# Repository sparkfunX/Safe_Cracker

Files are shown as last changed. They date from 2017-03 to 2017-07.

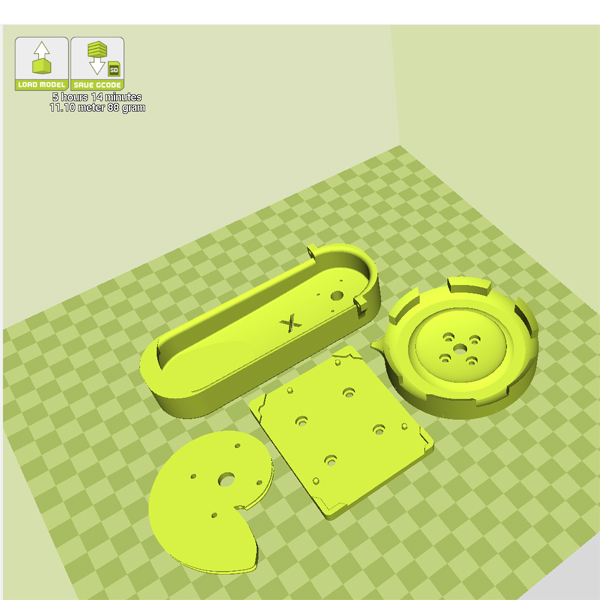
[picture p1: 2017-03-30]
3D/Safe3Dpieces.jpg

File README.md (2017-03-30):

SparkFun Safe Cracker
===========================================================

SparkFun Safe Cracker

A robot with some tricks to open combination safes.

We were able to crack our Craigslist safe in 40 minutes and 42 seconds! You can [re-watch the live cracking](https://www.youtube.com/watch?v=AsVSEHv2N4M) if you'd like. The magic moment occurs at [45:20](https://www.youtube.com/watch?v=AsVSEHv2N4M&t=45m10s) but start around [44:30](https://www.youtube.com/watch?v=AsVSEHv2N4M&t=44m30s) to get the full scope of what's going on.

The full tutorial is [here](https://learn.sparkfun.com/tutorials/building-a-safe-cracking-robot).

Repository Contents
-------------------

* **/Hardware** - The layout of the Safe Cracker shield in EAGLE PCB
* **/Firmware** - Source code that runs on the [RedBoard](https://www.sparkfun.com/products/13975)
* **/3D** - STL files for the dial coupler, handle puller, nautilus horn, and electronics base plate
* **live_crack_serial.log** - Output from the robot during the live stream.

License Information
-------------------

This project is _**open source**_! 

Please use, reuse, and modify these files as you see fit. Please maintain attribution to SparkFun Electronics and release anything derivative under the same license.

Distributed as-is; no warranty is given.

- Your friends at SparkX

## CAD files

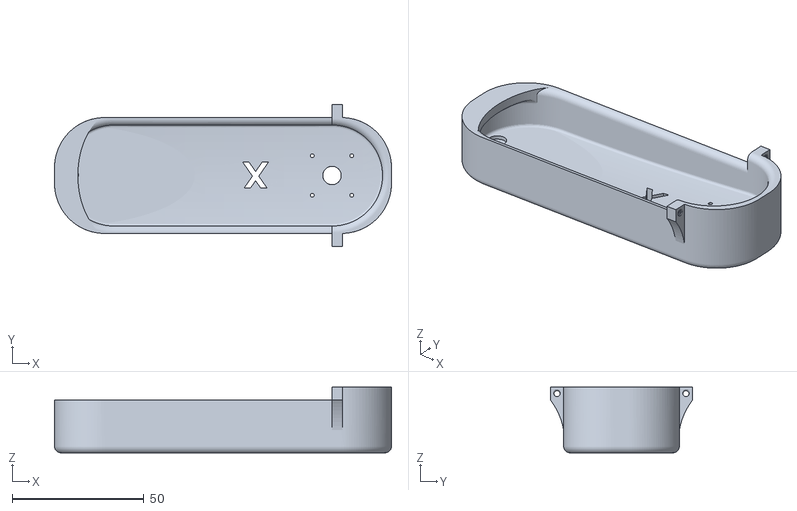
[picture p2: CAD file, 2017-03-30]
3D/SafeHandleMain.stl
128.0 x 53.9 x 25.0

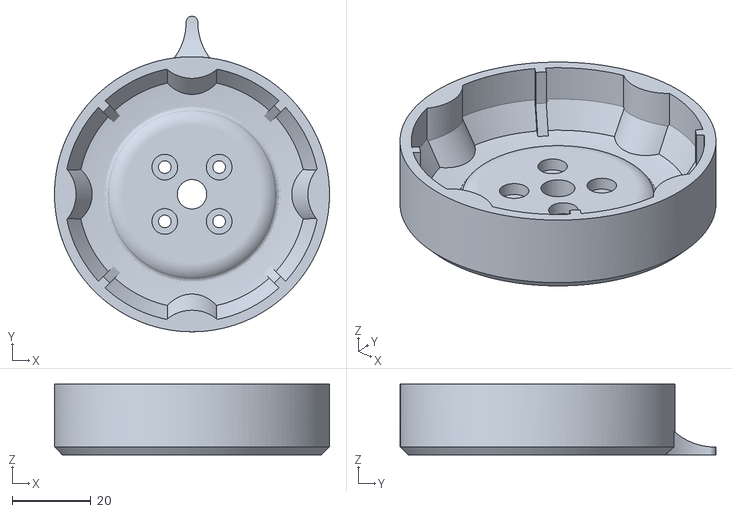
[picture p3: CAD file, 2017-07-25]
3D/DialForNewSentrySafe.stl
70.0 x 80.3 x 18.0

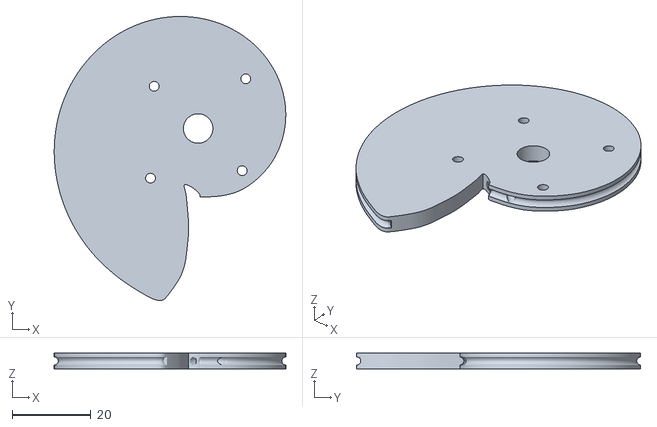
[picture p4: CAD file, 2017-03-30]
3D/NautilusPulley.stl
58.9 x 72.2 x 4.00

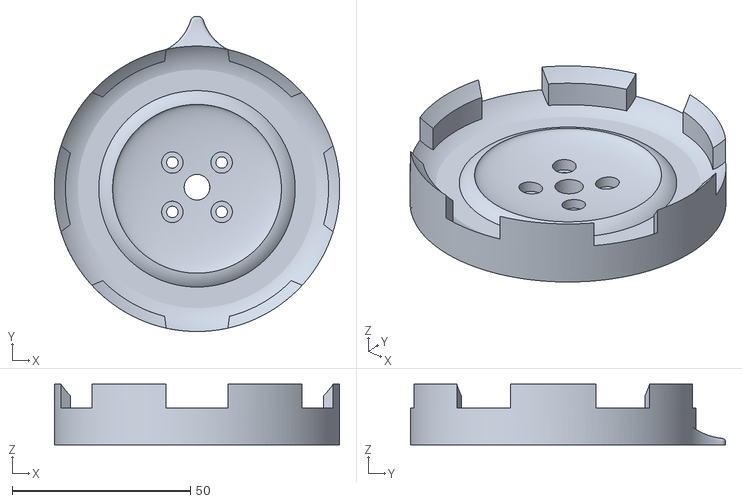
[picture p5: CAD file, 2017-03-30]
3D/SafeCrackerDial3.stl
80.0 x 88.3 x 17.0

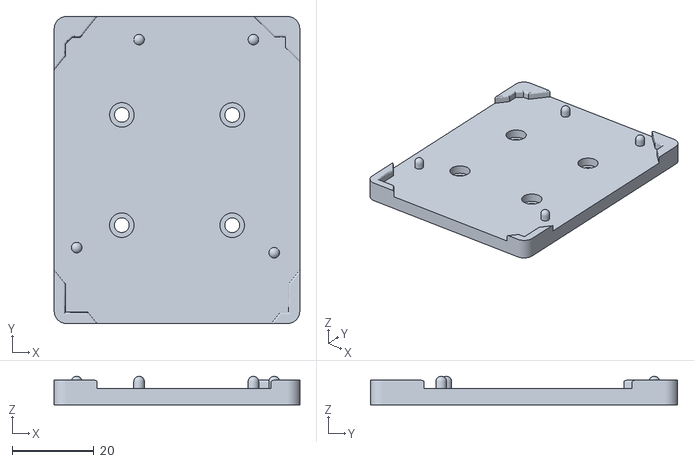
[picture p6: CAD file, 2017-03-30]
3D/SafeCrackerArduinoMount.stl
60.0 x 75.0 x 6.97

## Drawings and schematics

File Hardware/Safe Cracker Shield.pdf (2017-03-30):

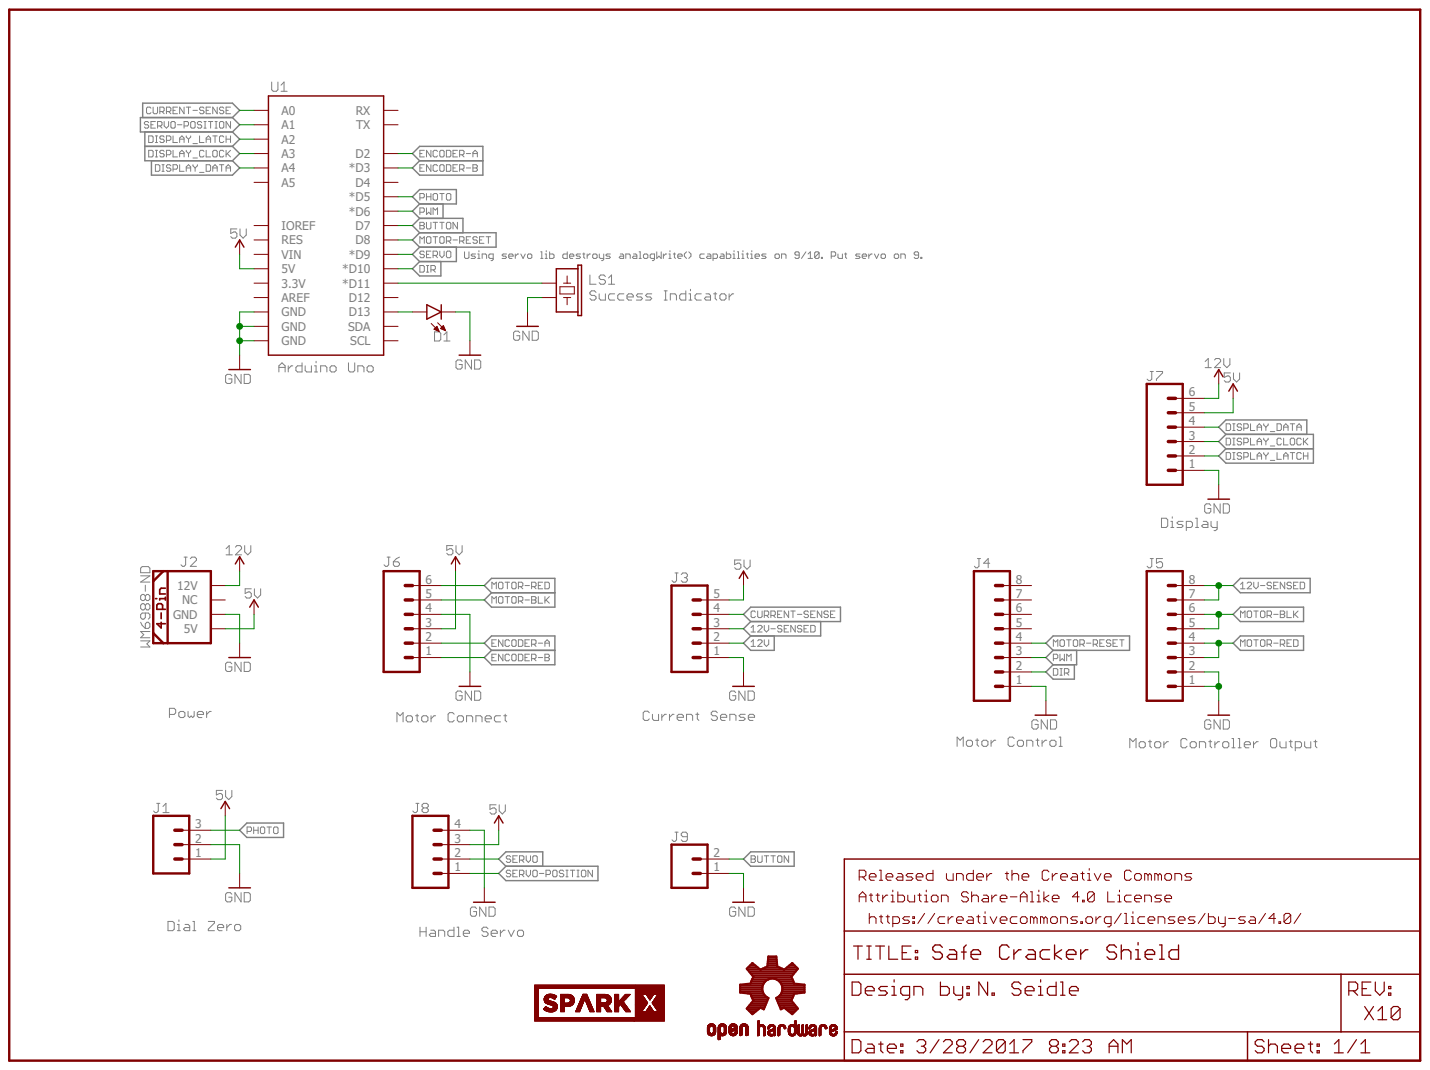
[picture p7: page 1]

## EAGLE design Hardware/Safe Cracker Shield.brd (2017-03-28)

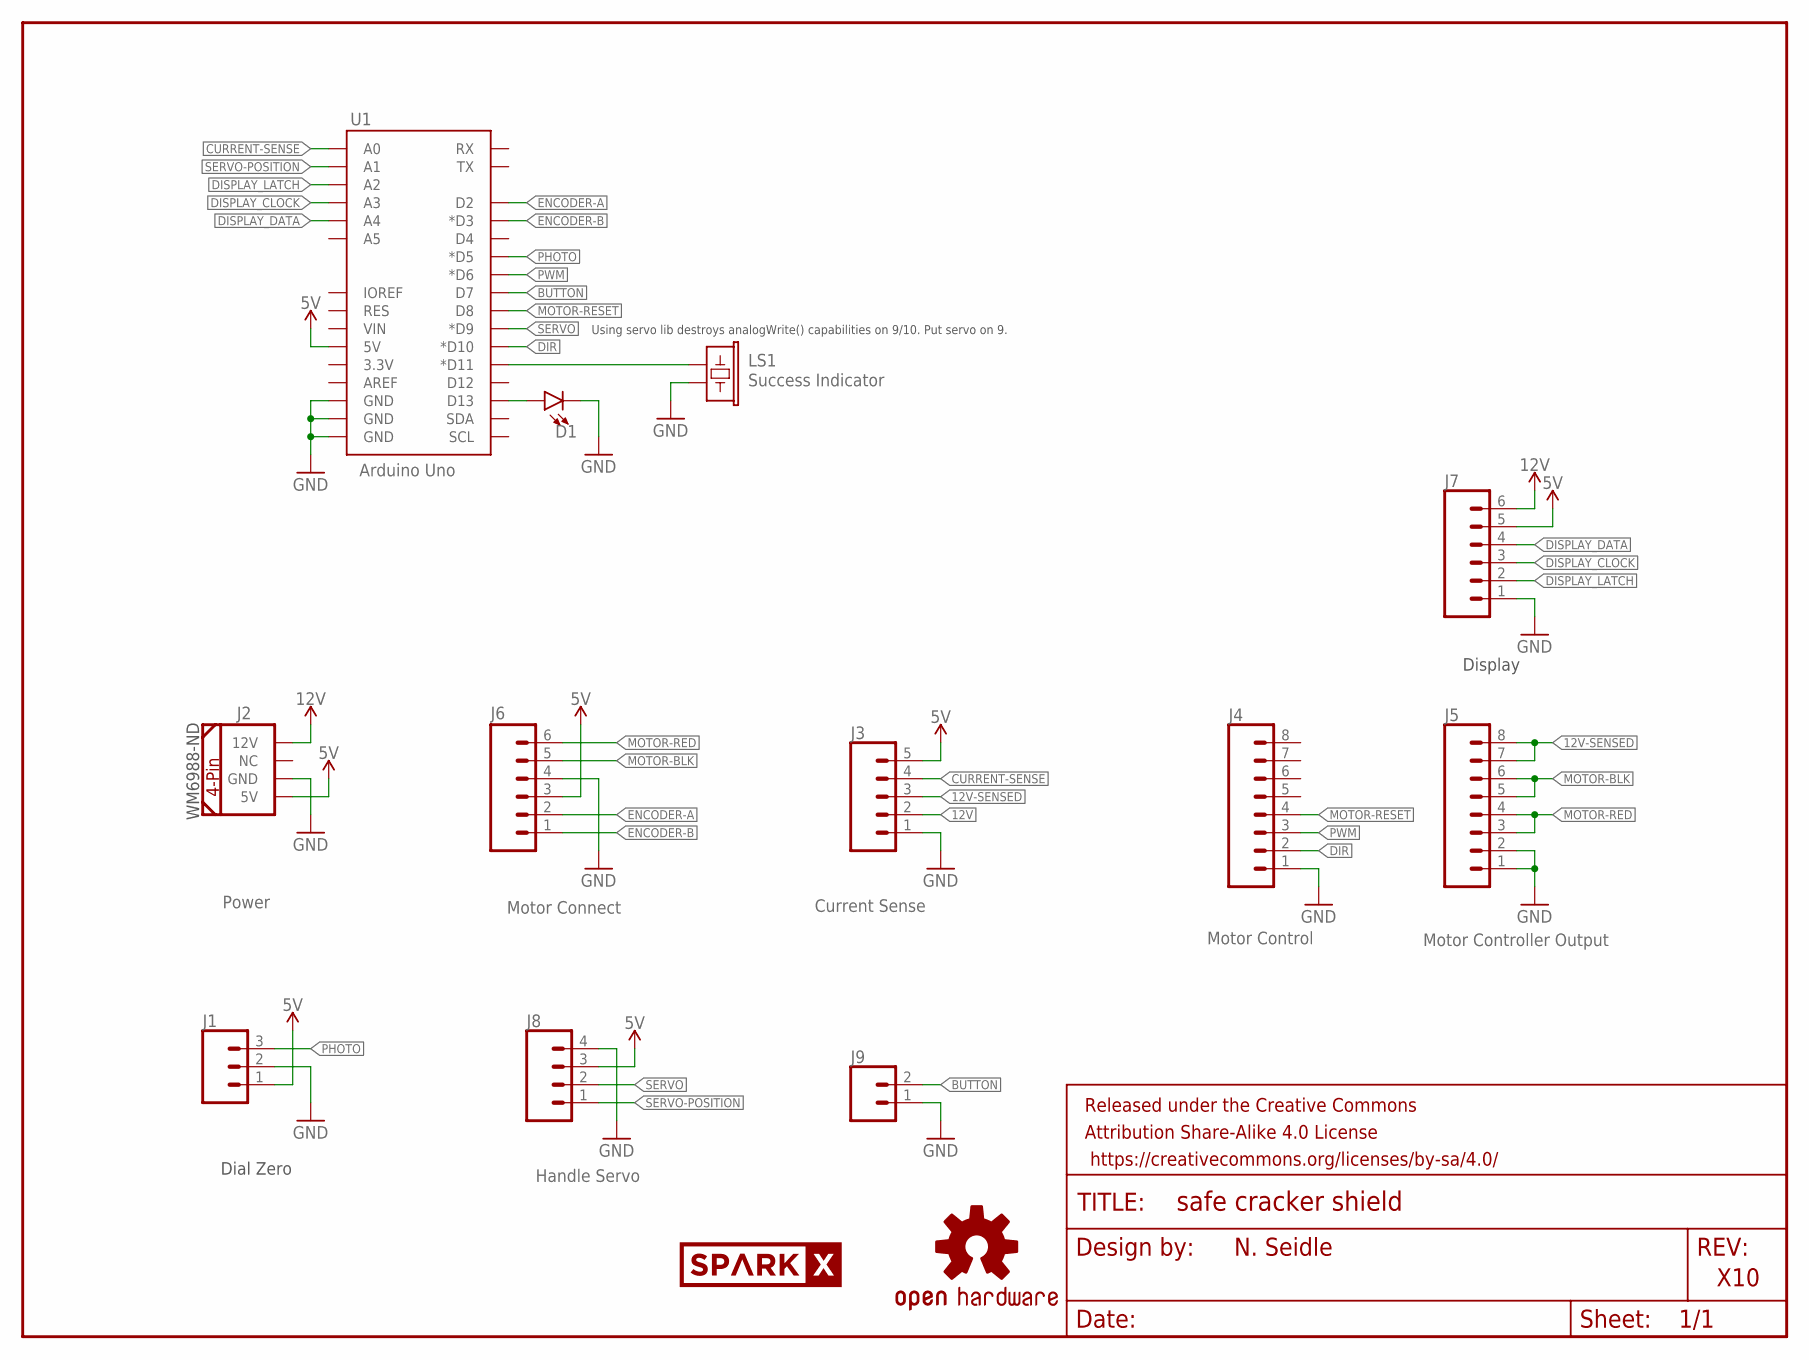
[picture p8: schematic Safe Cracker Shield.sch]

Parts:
D1: LED5MM; LED_5MM
FRAME1: FRAME-LETTER; CREATIVE_COMMONS
J1: CONN_03JST-PTH-VERT; JST-3-PTH-VERT
J2: Power; COMPUTER-PERIPHERAL-POWER-RA
J3: Current Sense; 1X05
J4: Motor Control; 1X08
J5: Motor Controller Output; 1X08
J6: Motor Connect; 1X06@1
J7: CONN_06SILK_FEMALE_PTH; 1X06
J8: Handle Servo; 1X04
J9: CONN_02JST-PTH-VERT; JST-2-PTH-VERT
LOGO2: OSHW-LOGOS; OSHW-LOGO-S
LS1: Success Indicator; BUZZER-12MM
U1: Arduino Uno; UNO_R3_SHIELD_NOLABELS
U$1: SPARKX-LOGO5; SPARKX-LARGE

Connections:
5V: J1.1, J2.5V, J3.5, J6.3, J7.5, J8.3, U1.5V
12V: J2.12V, J3.2, J7.6
12V-SENSED: J3.3, J5.7, J5.8
BUTTON: J9.2, U1.D7
BUZZ: LS1.+ (1), U1.D11 (*D11)
CURRENT-SENSE: J3.4, U1.A0
DIR: J4.2, U1.D10 (*D10)
DISPLAY_CLOCK: J7.3, U1.A3
DISPLAY_DATA: J7.4, U1.A4
DISPLAY_LATCH: J7.2, U1.A2
ENCODER-A: J6.2, U1.D2
ENCODER-B: J6.1, U1.D3 (*D3)
GND: D1.K (C), J1.2, J2.GND, J3.1, J4.1, J5.1, J5.2, J6.4, J7.1, J8.4, J9.1, LS1.- (2), U1.GND@0 (GND), U1.GND@1 (GND), U1.GND@2 (GND)
MOTOR-BLK: J5.5, J5.6, J6.5
MOTOR-RED: J5.3, J5.4, J6.6
MOTOR-RESET: J4.4, U1.D8
unnamed: D1.A, U1.D13
PHOTO: J1.3, U1.D5 (*D5)
PWM: J4.3, U1.D6 (*D6)
SERVO: J8.2, U1.D9 (*D9)
SERVO-POSITION: J8.1, U1.A1

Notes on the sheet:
WM6988-ND
N. Seidle
X10
Using servo lib destroys analogWrite() capabilities on 9/10. Put servo on 9.
Dial Zero
Display

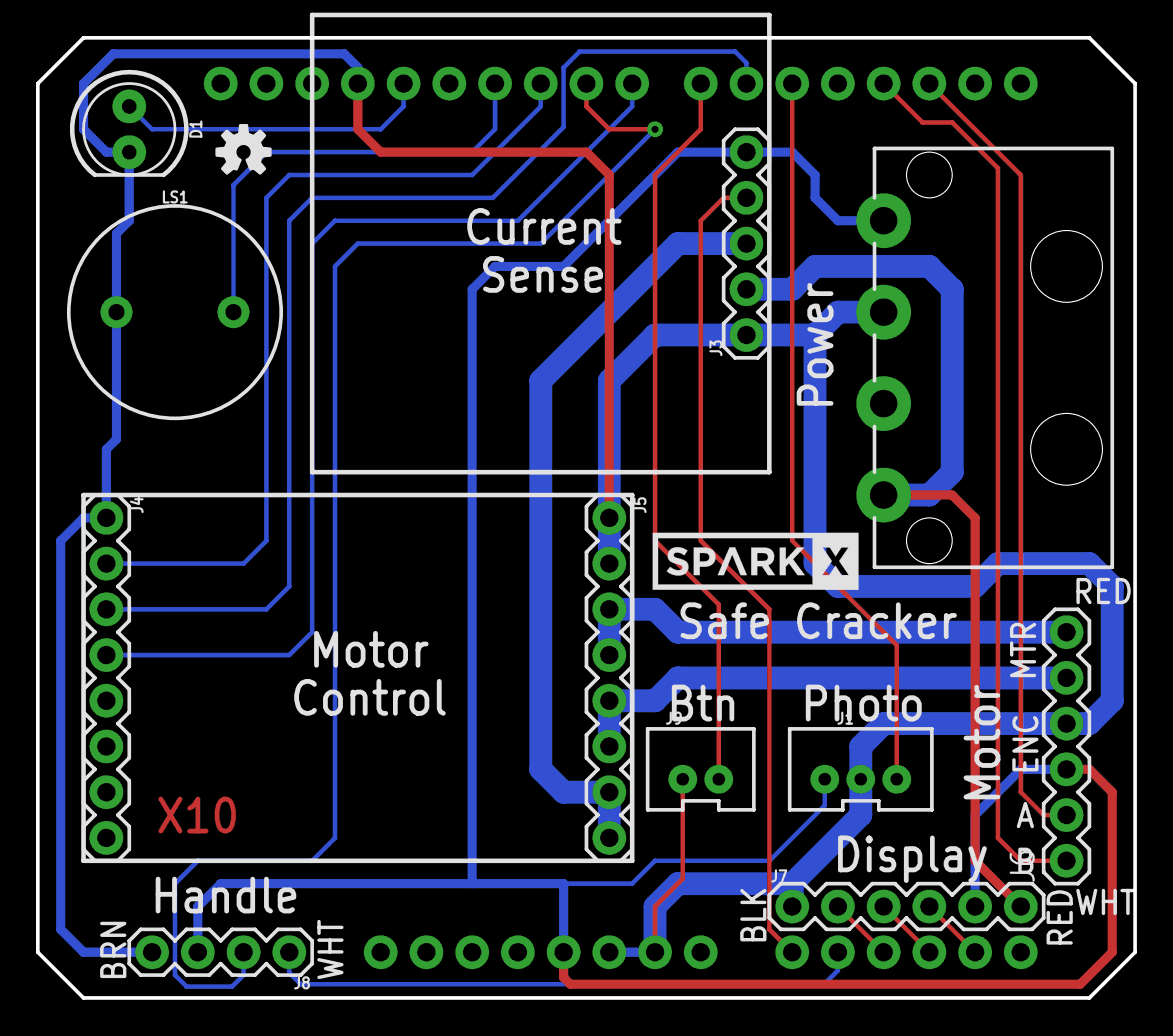
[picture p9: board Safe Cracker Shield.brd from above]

Board: 2 copper layers, 61.0 x 53.3 mm, 15 parts (0 on the bottom side), 21 nets.

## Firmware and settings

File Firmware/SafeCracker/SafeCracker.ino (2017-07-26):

/*
  Opening a safe using a motor and a servo
  By: Nathan Seidle @ SparkFun Electronics
  Date: February 24th, 2017

  We use a motor with encoder feedback to try to glean the internal workings of the
  safe to reduce the overall solution domain. Then we begin running through
  solution domain, pulling on the handle and measuring it as we go.

  Motor current turning dial, speed = 255, ~350 to 560mA
  Motor current turning dial, speed = 50, = ~60 to 120mA

  TODO:
  servo rest, pull, and open settings to eeprom
  current combination to nvm
*/

#include "nvm.h" //EEPROM locations for settings
#include <EEPROM.h> //For storing settings and things to NVM

#include <Servo.h>
Servo handleServo;

//Pin definitions
const byte encoderA = 2;
const byte encoderB = 3;
const byte photo = 5;
const byte motorPWM = 6;
const byte button = 7;
const byte motorReset = 8;
const byte servo = 9;
const byte motorDIR = 10;
const byte buzzer = 11;
const byte LED = 13;

const byte currentSense = A0;
const byte servoPositionButton = A1;
const byte displayLatch = A2;
const byte displayClock = A3;
const byte displayData = A4;

//Servo values are found using the testServo() function while the
//cracker was deattached from the safe

//Default settings for 0.8 cubic ft. safe
//On the 1st configuration increasing numbers cause handle to go down
//const byte servoRestingPosition = 15; //Position not pulling/testing on handle
//const byte servoPressurePosition = 50; //Position when doing indent measuring
//const byte servoTryPosition = 80; //Position when testing handle

//Default settings for 1.2 cubic ft. safe
//On the 2nd larger configuration, decreasing numbers cause handle to go down
int servoRestingPosition = 100; //Position not pulling/testing on handle
int servoTryPosition = 50; //Position when testing handle
int servoHighPressurePosition = 40; //Position when doing indent measuring

const int timeServoApply = 350;  //ms for servo to apply pressure. 350 works
const int timeServoRelease = 250;  //Allow servo to release. 250 works
const int timeMotorStop = 125; //ms for motor to stop spinning after stop command. 200 works

int handlePosition; //Used to see how far handle moved when pulled on
//const int handleOpenPosition = 187; //Analog value. Must be less than analog value from servo testing.

#define CCW 0
#define CW 1

volatile int steps = 0; //Keeps track of encoder counts. 8400 per revolution so this can get big.
boolean direction = CW; //steps goes up or down based on direction
boolean previousDirection = CW; //Detects when direction changes to add some steps for encoder slack
byte homeOffset = 0; //Found by running findFlag(). Stored in nvm.

//Because we're switching directions we need to add extra steps to take
//up the slack in the encoder
//The greater the adjustment the more negative it goes
int switchDirectionAdjustment = (84 * 0) + 0; //Use 'Test dial control' to determine adjustment size
//84 * 1 - 20 = Says 34 but is actually 33.5 (undershoot)
//84 * 0 = Says 85 but is actually 85.9 (overshoot)

//DiscA goes in CCW fashion during testing, increments 3 each new try.
//We don't know if this is the center of the notch. If you exhaust the combination domain, adjust up or down one.
#define DISCA_START 0

//DiscB goes in CW fashion during testing, increments 3 each new try.
#define DISCB_START (DISCA_START - 3)

//DiscC goes in CCW fashion during testing. 12 indentations, 12 raised bits. Indents are 4.17 numbers wide.
#define DISCC_START 0

//These are the combination numbers we are attempting
int discA = DISCA_START;
int discB = DISCB_START;
int discC = DISCC_START;

//int discA = 30; //Testing only. Don't use.
//int discB = 55;
//int discC = 47;

//Keeps track of the combos we need to try for each disc
//byte maxAAttempts = 33; //Assume solution notch is 3 digits wide
//byte maxBAttempts = 33; //Assume solution notch is 3 digits wide
byte maxCAttempts = 0; //Calculated at startup

//Keeps track of how many combos we've tried on a given disc
//byte discAAttempts = 0;
//byte discBAttempts = 0;
byte discCAttempts = 0;

long startTime; //Used to measure amount of time taken per test

boolean buttonPressed = false; //Keeps track of the 'GO' button.

boolean indentsToTry[12]; //Keeps track of the indents we want to try
int indentLocations[12]; //Encoder click for a given indent
int indentWidths[12]; //Calculated width of a given indent
int indentDepths[12]; //Not really used

void setup()
{
  Serial.begin(115200);
  Serial.println();
  Serial.println();
  Serial.println("Safe Cracker");

  pinMode(motorReset, OUTPUT);
  disableMotor();

  pinMode(encoderA, INPUT);
  pinMode(encoderB, INPUT);

  pinMode(motorPWM, OUTPUT);
  pinMode(motorDIR, OUTPUT);

  pinMode(LED, OUTPUT);

  pinMode(currentSense, INPUT);
  pinMode(servoPositionButton, INPUT_PULLUP);

  pinMode(photo, INPUT_PULLUP);

  pinMode(button, INPUT_PULLUP);

  pinMode(displayClock, OUTPUT);
  pinMode(displayLatch, OUTPUT);
  pinMode(displayData, OUTPUT);

  digitalWrite(displayClock, LOW);
  digitalWrite(displayLatch, LOW);
  digitalWrite(displayData, LOW);

  //Setup the encoder interrupts.
  attachInterrupt(digitalPinToInterrupt(encoderA), countA, CHANGE);
  attachInterrupt(digitalPinToInterrupt(encoderB), countB, CHANGE);

  //Load settings from EEPROM
  homeOffset = EEPROM.read(LOCATION_HOME_OFFSET); //After doing a findFlag calibration, adjust this number up or down until dial is at zero
  Serial.print(F("Home Offset: "));
  Serial.println(homeOffset);

  Serial.println(F("Indent data"));
  for (int indentNumber = 0 ; indentNumber < 12 ; indentNumber++)
  {
    //Load the yes/no for each indent To Try
    indentsToTry[indentNumber] = EEPROM.read(LOCATION_TEST_INDENT_0 + indentNumber); //Boolean
    
    //Get the encoder values for each indent
    EEPROM.get(LOCATION_INDENT_DIAL_0 + (indentNumber * 2), indentLocations[indentNumber]); //Addr, loc. Encoder click for a given indent

    Serial.print(F("IndentNum["));
    Serial.print(indentNumber);
    Serial.print(F("] Encoder["));
    Serial.print(indentLocations[indentNumber]);
    Serial.print(F("] / Dial["));
    Serial.print(convertEncoderToDial(indentLocations[indentNumber]));
    Serial.print(F("] / Width["));
    Serial.print(indentWidths[indentNumber]);
    Serial.print(F("] / Depth["));
    Serial.print(indentDepths[indentNumber]);
    Serial.print(F("] Test["));

    //Print Test if indent will be tested
    if (indentsToTry[indentNumber] == true) Serial.print("Y");
    else Serial.print("N");
    Serial.print(F("]"));

    Serial.println();

  }

  //Get servo settings
  EEPROM.get(LOCATION_SERVO_REST, servoRestingPosition);
  EEPROM.get(LOCATION_SERVO_TEST_PRESSURE, servoTryPosition);
  EEPROM.get(LOCATION_SERVO_HIGH_PRESSURE, servoHighPressurePosition);

  //Validate settings
  if (servoRestingPosition > 250 || servoRestingPosition < 0)
  {
    //New board and/or EEPROM has not been set
    //Assign defaults
    servoRestingPosition = 100;
    servoTryPosition = 50;
    servoHighPressurePosition = 40;

    //Record these defaults to EEPROM
    EEPROM.put(LOCATION_SERVO_REST, servoRestingPosition); //addr, data
    EEPROM.put(LOCATION_SERVO_TEST_PRESSURE, servoTryPosition);
    EEPROM.put(LOCATION_SERVO_HIGH_PRESSURE, servoHighPressurePosition);
  }

  Serial.print(F("servo: resting["));
  Serial.print(servoRestingPosition);
  Serial.print(F("] try["));
  Serial.print(servoTryPosition);
  Serial.print(F("] HighPressure["));
  Serial.print(servoHighPressurePosition);
  Serial.print(F("]"));
  Serial.println();

  //Setup servo
  handleServo.attach(servo);
  handleServo.write(servoRestingPosition); //Goto the resting position (handle horizontal, door closed)
  delay(timeServoRelease * 3); //Allow servo to release, may be in solution slot

  randomSeed(analogRead(A5));

  //Calculate how many indents we need to attempt on discC
  maxCAttempts = 0;
  for (byte x = 0 ; x < 12 ; x++)
    if (indentsToTry[x] == true) maxCAttempts++;

  //At startup discB may be negative. Fix it.
  if (discB < 0) discB += 100;

  //Tell dial to go to zero
  enableMotor(); //Turn on motor controller
  findFlag(); //Find the flag
  //Adjust steps with the real-world offset
  steps = (84 * homeOffset); //84 * the number the dial sits on when 'home'
  setDial(0, false); //Make dial go to zero

  clearDisplay();
  showCombination(0, 0, 0); //Display zeroes
}

void loop()
{
  char incoming;

  //Main serial control menu
  Serial.println();
  Serial.print(F("Combo to start at: "));
  Serial.print(discA);
  Serial.print("/");
  Serial.print(discB);
  Serial.print("/");
  Serial.print(discC);
  Serial.println();

  Serial.println(F("1) Go home and reset dial"));
  Serial.println(F("2) Test dial control"));
  Serial.println(F("3) View indent positions"));
  Serial.println(F("4) Measure indents"));
  Serial.println(F("5) Set indents to test"));
  Serial.println(F("6) Set starting combos"));
  Serial.println(F("7) Calibrate handle servo"));
  Serial.println(F("8) Test handle button"));
  Serial.println(F("9) Test indent centers"));
  Serial.println(F("s) Start cracking"));

  while (!Serial.available())
  {
    if (digitalRead(button) == LOW)
    {
      delay(50);
      if (digitalRead(button) == LOW)
      {
        buttonPressed = true;
        break;
      }
      else
      {
        buttonPressed = false;
      }
    }
    else
    {
      buttonPressed = false;
    }
  }

  if (buttonPressed == true)
  {
    Serial.println(F("Button pressed!"));

    while (digitalRead(button) == false); //Wait for user to stop pressing button
    buttonPressed = false; //Reset variable

    incoming = 's'; //Act as if user pressed start cracking
  }
  else
  {
    incoming = Serial.read();
  }

  if (incoming == '1')
  {
    //Go to starting conditions
    findFlag(); //Detect the flag and center the dial

    Serial.print(F("Home offset is: "));
    Serial.println(homeOffset);

    int zeroLocation = 0;
    while (1) //Loop until we have good input
    {
      Serial.print(F("Enter where dial is actually at: "));

      while (!Serial.available()); //Wait for user input

      Serial.setTimeout(1000); //Must be long enough for user to enter second character
      zeroLocation = Serial.parseInt(); //Read user input

      Serial.print(zeroLocation);
      if (zeroLocation >= 0 && zeroLocation <= 99) break;
      Serial.println(F(" out of bounds"));
    }

    homeOffset = zeroLocation;

    Serial.print(F("\n\rSetting home offset to: "));
    Serial.println(homeOffset);

    EEPROM.write(LOCATION_HOME_OFFSET, homeOffset);

    //Adjust steps with the real-world offset
    steps = (84 * homeOffset); //84 * the number the dial sits on when 'home'

    setDial(0, false); //Turn to zero

    Serial.println(F("Dial should be at: 0"));
  }
  else if (incoming == '2')
  {
    positionTesting(); //Pick random places on dial and prove we can go to them
  }
  else if (incoming == '3')
  {
    //View indent center values
    for (int x = 0 ; x < 12 ; x++)
    {
      Serial.print(x);
      Serial.print(F(": ["));
      Serial.print(lookupIndentValues(x));
      Serial.print(F("]"));
      Serial.println();
    }
  }
  else if (incoming == '4')
  {
    //Measure indents

    int measurements = 0;
    while (1) //Loop until we have good input
    {
      Serial.print(F("How many measurements would you like to take? (Start with 1)"));
      while (!Serial.available()); //Wait for user input
      Serial.setTimeout(1000); //Must be long enough for user to enter second character
      measurements = Serial.parseInt(); //Read user input

      if (measurements >= 1 && measurements <= 20) break;

      Serial.print(measurements);
      Serial.println(F(" out of bounds"));
    }
    Serial.println(measurements);

    measureDiscC(measurements); //Try to measure the idents in disc C. Give function the number of tests to run (get average).
  }
  else if (incoming == '5')
  {
    while (1) //Loop until exit
    {
      int indent = 0;
      while (1) //Loop until we have valid input
      {
        Serial.println("Indents to test:");
        for (int x = 0 ; x < 12 ; x++)
        {
          Serial.print(x);
          Serial.print(": ");

          //Print Test if indent will be tested
          if (indentsToTry[x] == true) Serial.print("Y");
          else Serial.print("N");

          //Print dial value of this indent
          Serial.print(" / ");
          Serial.print(convertEncoderToDial(indentLocations[x]));

          Serial.println();
        }
        Serial.println("Which indent to change?");
        Serial.println("Type 99 to exit");

        while (!Serial.available()); //Wait for user input

        Serial.setTimeout(500); //Must be long enough for user to enter second character
        indent = Serial.parseInt(); //Read user input

        if (indent >= 0 && indent <= 11) break;
        if (indent == 99) break;

        Serial.print(indent);
        Serial.println(F(" out of bounds"));
      }

      if (indent == 99) break; //User wants to exit

      //Flip it
      if (indentsToTry[indent] == true) indentsToTry[indent] = false;
      else indentsToTry[indent] = true;

      //Record current settings to EEPROM
      EEPROM.put(LOCATION_TEST_INDENT_0 + indent, indentsToTry[indent]);
    }

    //Calculate how many indents we need to attempt on discC
    maxCAttempts = 0;
    for (byte x = 0 ; x < 12 ; x++)
      if (indentsToTry[x] == true) maxCAttempts++;
  }
  else if (incoming == '6')
  {
    //Set starting combos
    for (byte x = 0 ; x < 3 ; x++)
    {
      int combo = 0;
      while (1) //Loop until we have good input
      {
        Serial.print(F("Enter Combination "));
        if (x == 0) Serial.print("A");
        else if (x == 1) Serial.print("B");
        else if (x == 2) Serial.print("C");
        Serial.print(F(" to start at: "));
        while (!Serial.available()); //Wait for user input

        Serial.setTimeout(1000); //Must be long enough for user to enter second character
        combo = Serial.parseInt(); //Read user input

        if (combo >= 0 && combo <= 99) break;

        Serial.print(combo);
        Serial.println(F(" out of bounds"));
      }
      Serial.println(combo);
      if (x == 0) discA = combo;
      else if (x == 1) discB = combo;
      else if (x == 2) discC = combo;
    }

  }
  else if (incoming == '7')
  {
    testServo();
  }
  else if (incoming == '8')
  {
    testHandleButton(); //Just pull down on handle and vary distance to hit open button
  }
  else if (incoming == '9')
  {

    setDial(0, false); //Turn to zero without extra spin

    //Test center point of each indent
    for (int indentNumber = 0 ; indentNumber < 12 ; indentNumber++)
    {

      //int dialValue = lookupIndentValues(indentNumber); //Get this indent's dial value
      //setDial(dialValue, false); //Go to the middle of this indent's location

      int encoderValue;
      EEPROM.get(LOCATION_INDENT_DIAL_0 + (indentNumber * 2), encoderValue);

      //84 allows bar to hit indent but just barely
      //* 2 lines the bar with indent nicely
      encoderValue += 84 * 2;

      gotoStep(encoderValue, false); //Goto that encoder value, no extra spin

      Serial.print("dialValue: ");
      Serial.print(convertEncoderToDial(encoderValue));

      Serial.print(" encoderValue: ");
      Serial.println(encoderValue);

      handleServo.write(servoTryPosition); //Apply pressure to handle
      delay(timeServoApply); //Wait for servo to move
      handleServo.write(servoRestingPosition); //Release servo
      delay(timeServoRelease); //Allow servo to release
    }
    Serial.println();

  }
  else if (incoming == 'a')
  {
    handleServo.write(servoRestingPosition);
  }
  else if (incoming == 'z')
  {
    handleServo.write(servoTryPosition);
  }
  else if (incoming == 's') //Start cracking!
  {
    clearDisplay();
    showCombination(discA, discB, discC); //Update display

    startTime = millis();

    //Set the discs to the current combinations (user can set if needed from menu)
    resetDiscsWithCurrentCombo(false); //Do not pause with messages

    while (1)
    {
      nextCombination(); //Try the next combo!

      if (Serial.available())
      {
        byte incoming = Serial.read();
        if (incoming == 'p')
        {
          Serial.println(F("Pausing"));
          while (!Serial.available());
          Serial.read();
          Serial.println(F("Running"));
        }
        else if (incoming == 'x' || incoming == 's')
        {
          Serial.println(F("Cracking stopped"));
          break; //User wants to stop
        }
      }
    } //End eombination loop
  } //End incoming == 's'
}

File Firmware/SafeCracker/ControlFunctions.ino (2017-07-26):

/*
  These are the general control functions

  setDial - go to a given dial position (0 to 99)
  resetDial - spin the dial twice to move reset discs A, B, and C. Stop at 0.
  findFlag - tell dial to return to where the flag interruts the photogate. Depending on how the robot is attached to dial, this may be true zero or an offset
  setDiscsToStart - Go home, clear dial, go to starting numbers

  Supporting functions:
  gotoStep - go to a certain step value out of 8400. The DC motor has momentum so this function, as best as possible, goes to a step value
  stepRequired - calcs the steps of the encoder to get from current position to a given position
  convertDialToEncoder - given a dial number, how many encoder steps is that?
  convertEncoderToDial - given encoder value, what is the dial position?
  enable/disableMotor - controls the enable pin on motor driver
  turnCW/CCW - controls the direction pin on motor driver

*/

//Given a step value, go to that step
//Assume user has set direction prior to calling
//Returns the delta from what you asked and where it ended up
//Adding a full rotation will add a 360 degree full rotation
int gotoStep(int stepGoal, boolean addAFullRotation)
{
  //Coarse speed and window control how fast we arrive at the digit on the dial
  //Having too small of a window or too fast of an attack will make the dial
  //overshoot.
  int coarseSpeed = 200; //Speed at which we get to coarse window (0-255). 150, 200 works. 210, 230 fails
  int coarseWindow = 1250; //Once we are within this amount, switch to fine adjustment
  int fineSpeed = 50; //Less than 50 may not have enough torque
  int fineWindow = 32; //One we are within this amount, stop searching

  //Because we're switching directions we need to add extra steps to take
  //up the slack in the encoder
  if (direction == CW && previousDirection == CCW)
  {
    steps += switchDirectionAdjustment;
    if (steps > 8400) steps -= 8400;
    previousDirection = CW;
  }
  else if (direction == CCW && previousDirection == CW)
  {
    steps -= switchDirectionAdjustment;
    if (steps < 0) steps += 8400;
    previousDirection = CCW;
  }

  setMotorSpeed(coarseSpeed); //Go!
  while (stepsRequired(steps, stepGoal) > coarseWindow) ; //Spin until coarse window is closed

  //After we have gotten close to the first coarse window, proceed past the goal, then proceed to the goal
  if (addAFullRotation == true)
  {
    int tempStepGoal = steps + 8400/2; //Move 50 away from current position
    if (tempStepGoal > 8400) tempStepGoal -= 8400;
    
    //Go to temp position
    while (stepsRequired(steps, tempStepGoal) > coarseWindow) ; 
        
    //Go to stepGoal
    while (stepsRequired(steps, stepGoal) > coarseWindow) ; //Spin until coarse window is closed
  }

  setMotorSpeed(fineSpeed); //Slowly approach

  while (stepsRequired(steps, stepGoal) > fineWindow) ; //Spin until fine window is closed

  setMotorSpeed(0); //Stop

  delay(timeMotorStop); //Wait for motor to stop

  int delta = steps - stepGoal;

  /*if (direction == CW) Serial.print("CW ");
    else Serial.print("CCW ");
    Serial.print("stepGoal: ");
    Serial.print(stepGoal);
    Serial.print(" / Final steps: ");
    Serial.print(steps);
    Serial.print(" / delta: ");
    Serial.print(delta);
    Serial.println();*/

  return (delta);
}

//Calculate number of steps to get to our goal
//Based on current position, goal, and direction
//Corrects for 8400 roll over
int stepsRequired(int currentSteps, int goal)
{
  if (direction == CW)
  {
    if (currentSteps >= goal) return (currentSteps - goal);
    else if (currentSteps < goal) return (8400 - goal + currentSteps);
  }
  else if (direction == CCW)
  {
    if (currentSteps >= goal) return (8400 - currentSteps + goal);
    else if (currentSteps < goal) return (goal - currentSteps);
  }

  Serial.println(F("stepRequired failed")); //We shouldn't get this far
  Serial.print(F("Goal: "));
  Serial.println(goal);
  Serial.print(F("currentSteps: "));
  Serial.println(currentSteps);

  return (0);
}

//Given a dial number, goto that value
//Assume user has set the direction before calling
//Returns the dial value we actually ended on
int setDial(int dialValue, boolean extraSpin)
{
  //Serial.print("Want dialValue: ");
  //Serial.println(dialValue);

  int encoderValue = convertDialToEncoder(dialValue); //Get encoder value
  //Serial.print("Want encoderValue: ");
  //Serial.println(encoderValue);

  gotoStep(encoderValue, extraSpin); //Goto that encoder value
  //Serial.print("After movement, steps: ");
  //Serial.println(steps);

  int actualDialValue = convertEncoderToDial(steps); //Convert back to dial values
  //Serial.print("After movement, dialvalue: ");
  //Serial.println(actualDialValue);

  return (actualDialValue);
}

//Spin until we detect the photo gate trigger
void findFlag()
{
  byte fastSearch = 255; //Speed at which we locate photogate
  byte slowSearch = 50;

  turnCW();

  //If the photogate is already detected spin until we are out
  if (flagDetected() == true)
  {
    Serial.println(F("We're too close to the photogate"));
    int currentDial = convertEncoderToDial(steps);
    currentDial += 50;
    if (currentDial > 100) currentDial -= 100;
    setDial(currentDial, false); //Advance to 50 dial ticks away from here
  }

  //Begin spinning
  setMotorSpeed(fastSearch);

  while (flagDetected() == false) delayMicroseconds(1); //Spin freely

  //Ok, we just zipped past the gate. Stop and spin slowly backward
  setMotorSpeed(0);
  delay(timeMotorStop); //Wait for motor to stop spinning
  turnCCW();

  setMotorSpeed(slowSearch);
  while (flagDetected() == false) delayMicroseconds(1); //Find flag

  setMotorSpeed(0);
  delay(timeMotorStop); //Wait for motor to stop

  //Adjust steps with the real-world offset
  steps = (84 * homeOffset); //84 * the number the dial sits on when 'home'

  previousDirection = CCW; //Last adjustment to dial was in CCW direction
}

//Set the discs to the current combinations (user selectable)
void resetDiscsWithCurrentCombo(boolean pause)
{
  resetDial(); //Clear out everything

  //Set discs to this combo
  turnCCW();
  int discAIsAt = setDial(discA, false);
  Serial.print("DiscA is at: ");
  Serial.println(discAIsAt);
  if (pause == true) messagePause("Verify disc position");

  turnCW();
  //Turn past disc B one extra spin
  int discBIsAt = setDial(discB, true);
  Serial.print("DiscB is at: ");
  Serial.println(discBIsAt);
  if (pause == true) messagePause("Verify disc position");

  turnCCW();
  int discCIsAt = setDial(discC, false);
  Serial.print("DiscC is at: ");
  Serial.println(discCIsAt);
  if (pause == true) messagePause("Verify disc position");
  

  discCAttempts = -1; //Reset
}
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

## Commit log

2017-03-04 Initial dial-to-number working code and hardware.
    This code has many debug prints but finds home and dials directly to a
    number (works!).
    [Safe Cracker Shield.brd, Safe Cracker Shield.sch]
2017-03-04 Reorg file structure.
    [Safe Cracker Shield.GBL, Safe Cracker Shield.GBO, Safe Cracker Shield.GBS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]
2017-03-05 Added display and btn connectors
    [Safe Cracker Shield.GBL, Safe Cracker Shield.GBS, Safe Cracker Shield.GTL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]
2017-03-28 Fixed roll over indent count issue. Fixed net names on shield. Working version.
    [Safe Cracker Shield.brd, Safe Cracker Shield.sch]
2017-03-28 Fixed net names on display. Clean up hardware directory.
    [Safe Cracker Shield.GBL, Safe Cracker Shield.GBO, Safe Cracker Shield.GBS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]
2017-03-29 Fixing discB/C less than 3 cross over bug.
    [SafeCracker.ino, cracking.ino]
2017-03-30 Create STL files
2017-03-30 Adding log from live stream. Adding pdf schematic. Removed old files.
2017-03-30 Adding 3D files
    [NautilusPulley.stl, SafeCrackerArduinoMount.stl, SafeCrackerDial3.stl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]
2017-07-12 Indent detection working well. Cracks successfully.
    [ControlFunctions.ino, SafeCracker.ino, cracking.ino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]
2017-07-23 Find largest indent. New larger servo settings.
    Changed servo to 1/4 scale. Changed handle actuator. Getting offset to
    work correctly. General clean up.
    [ControlFunctions.ino, SafeCracker.ino, cracking.ino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]
2017-07-24 Convert to button for handle detection.
    Successfully cracks.
    [ControlFunctions.ino, SafeCracker.ino, cracking.ino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]
2017-07-24 Interference widths now working.
    DiscB now stops testing before interefering with discA. DiscC testing
    now works thru full set test without affecting discB.
    [ControlFunctions.ino, SafeCracker.ino, cracking.ino]
2017-07-24 Adding button testing function
    Used to calibrate height of success button
2017-07-24 Adding servo settings storage in EEPROM
2017-07-25 discB now behaves correctly during crossover of C.
    Reducing speed to increase accuracy. System now goes past 99 if
    necessary.
    [ControlFunctions.ino, SafeCracker.ino, cracking.ino]
2017-07-25 Add files via upload
    Adding new Dial Knob .stl file for the SentrySafe model #SFW123DTB
    [DialForNewSentrySafe.stl]
2017-07-26 Fixed indentToTry recording bug
    [ControlFunctions.ino, SafeCracker.ino, cracking.ino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]

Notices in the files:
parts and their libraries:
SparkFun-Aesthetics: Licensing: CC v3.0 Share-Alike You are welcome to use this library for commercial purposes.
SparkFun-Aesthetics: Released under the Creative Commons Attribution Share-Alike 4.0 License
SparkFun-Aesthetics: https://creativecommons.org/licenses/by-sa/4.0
